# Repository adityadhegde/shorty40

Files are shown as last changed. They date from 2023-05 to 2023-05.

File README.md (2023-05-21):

# The Shorty40
An ortholinear 39key keyboard with a 2U spacebar and KMK support using a Raspberry Pi Pico

## Bill of Materials

### Cost Saving Open Build
* Printed circuit board
* Raspberry Pi Pico or clones with same dimensions and GPIO Layouts with male headers attached 
* 39 1N4148 Diodes - through hole version
* 39 CherryMX Compatible plate mount switches
* 38 1U Keycaps and 1 2U Keycaps
* 1 2U plate mount stabilizer
* 1 3D Printed key plate
* 1 Laser Cut bottom plate
* 4 M2 Stand-Offs with  minimum 20mm clearance
* 8 5mm M2 screws
* 4 adhesive silicone/rubber foot - recommended but not required

### Close Case Build
* Printed circuit board
* Raspberry Pi Pico or clones with same dimensions and GPIO Layouts 
* 2 20 Pin male headers for the Pi Pico
* 2 20 Pin male to female headers for PCB
* 39 1N4148 Diodes - through hole version
* Hot Swap Sockets - tested with Millmax 0305 Socket
* 39 CherryMX Compatible plate mount switches
* 38 1U Keycaps and 1 2U Keycaps
* 1 2U plate mount stabilizer
* 1 3D Printed key plate
* 1 3D Printed Case - testing in process
* 8 5mm M2 screws
* 4 adhesive silicone/rubber foot

## Software Setup
1. Install [circuit python](https://circuitpython.org/)
2. Get [KMK](https://github.com/KMKfw/kmk_firmware/archive/refs/heads/master.zip) and unzip the files on to the circuit-python/pi-pico drive
3. Replace the code.py and boot.py files on the Pi-Pico drive with the ones provided on this repository

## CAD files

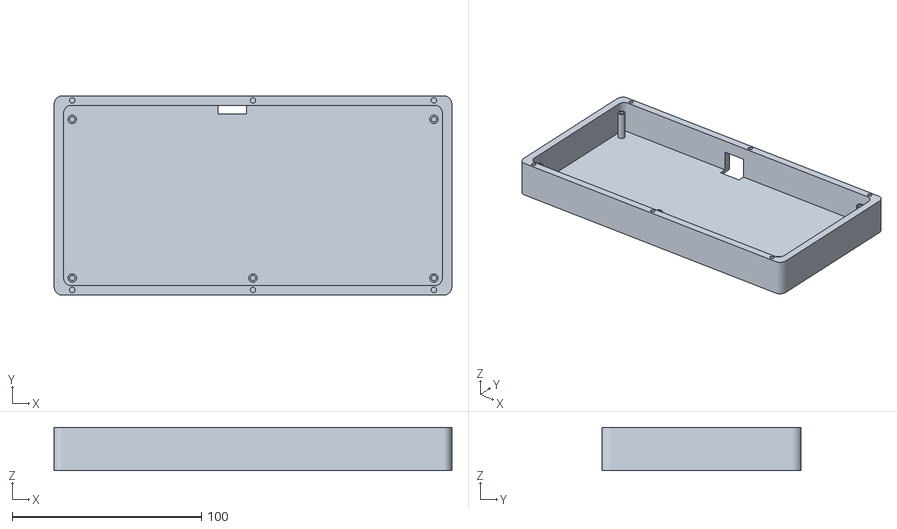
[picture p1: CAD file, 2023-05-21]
case.stl
210.5 x 105.4 x 23.0

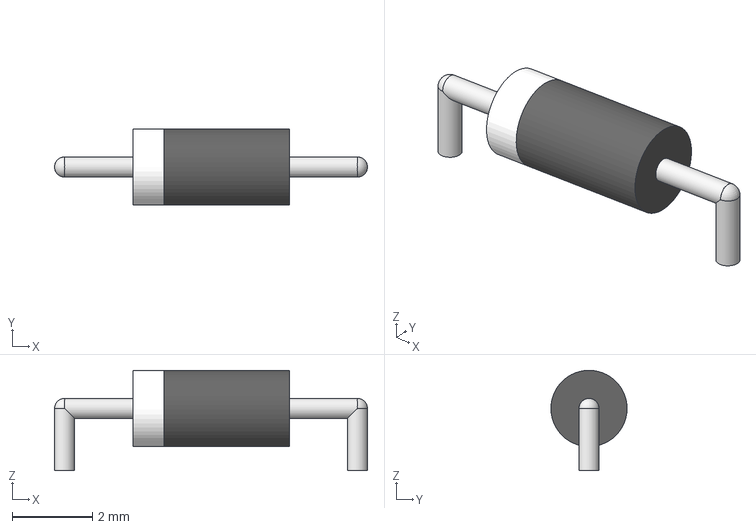
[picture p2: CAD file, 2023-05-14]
keeb/dioade/eec.models/Diotec_Semiconductor_-_1N4148.step
7.80 x 1.90 x 2.50 mm

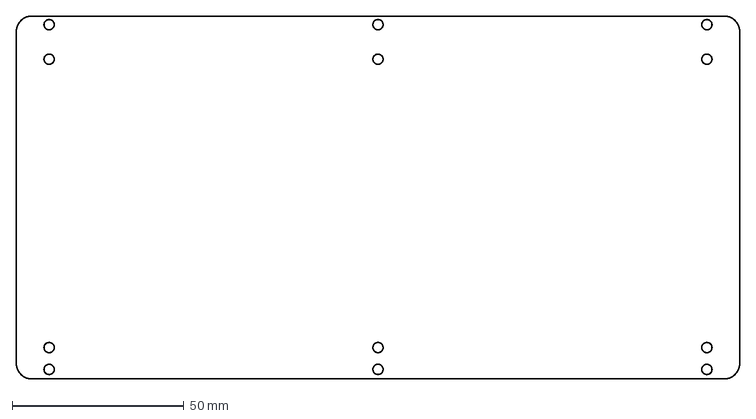
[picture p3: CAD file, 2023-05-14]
bottom_plate.dxf
210.5 x 105.4 mm

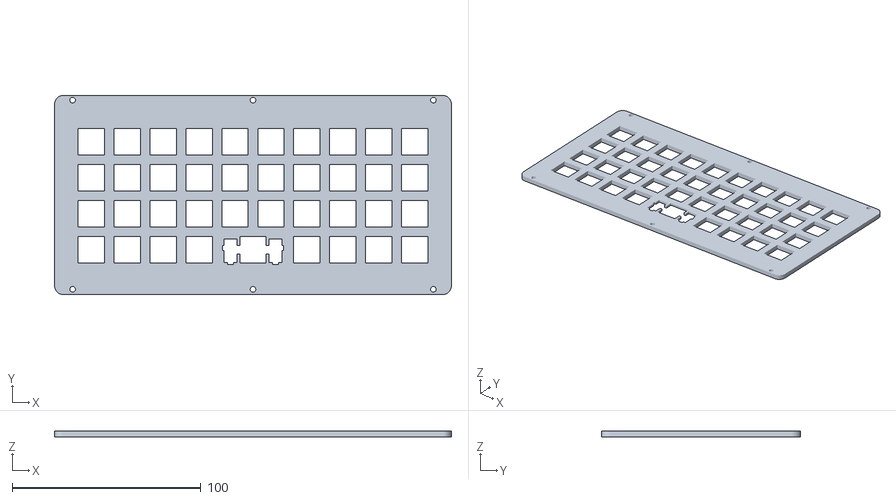
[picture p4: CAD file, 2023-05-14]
plate.stl
210.5 x 105.4 x 3.00

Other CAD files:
keeb/KiCad-RP-Pico-main/SketchUp Model/Pico.skp

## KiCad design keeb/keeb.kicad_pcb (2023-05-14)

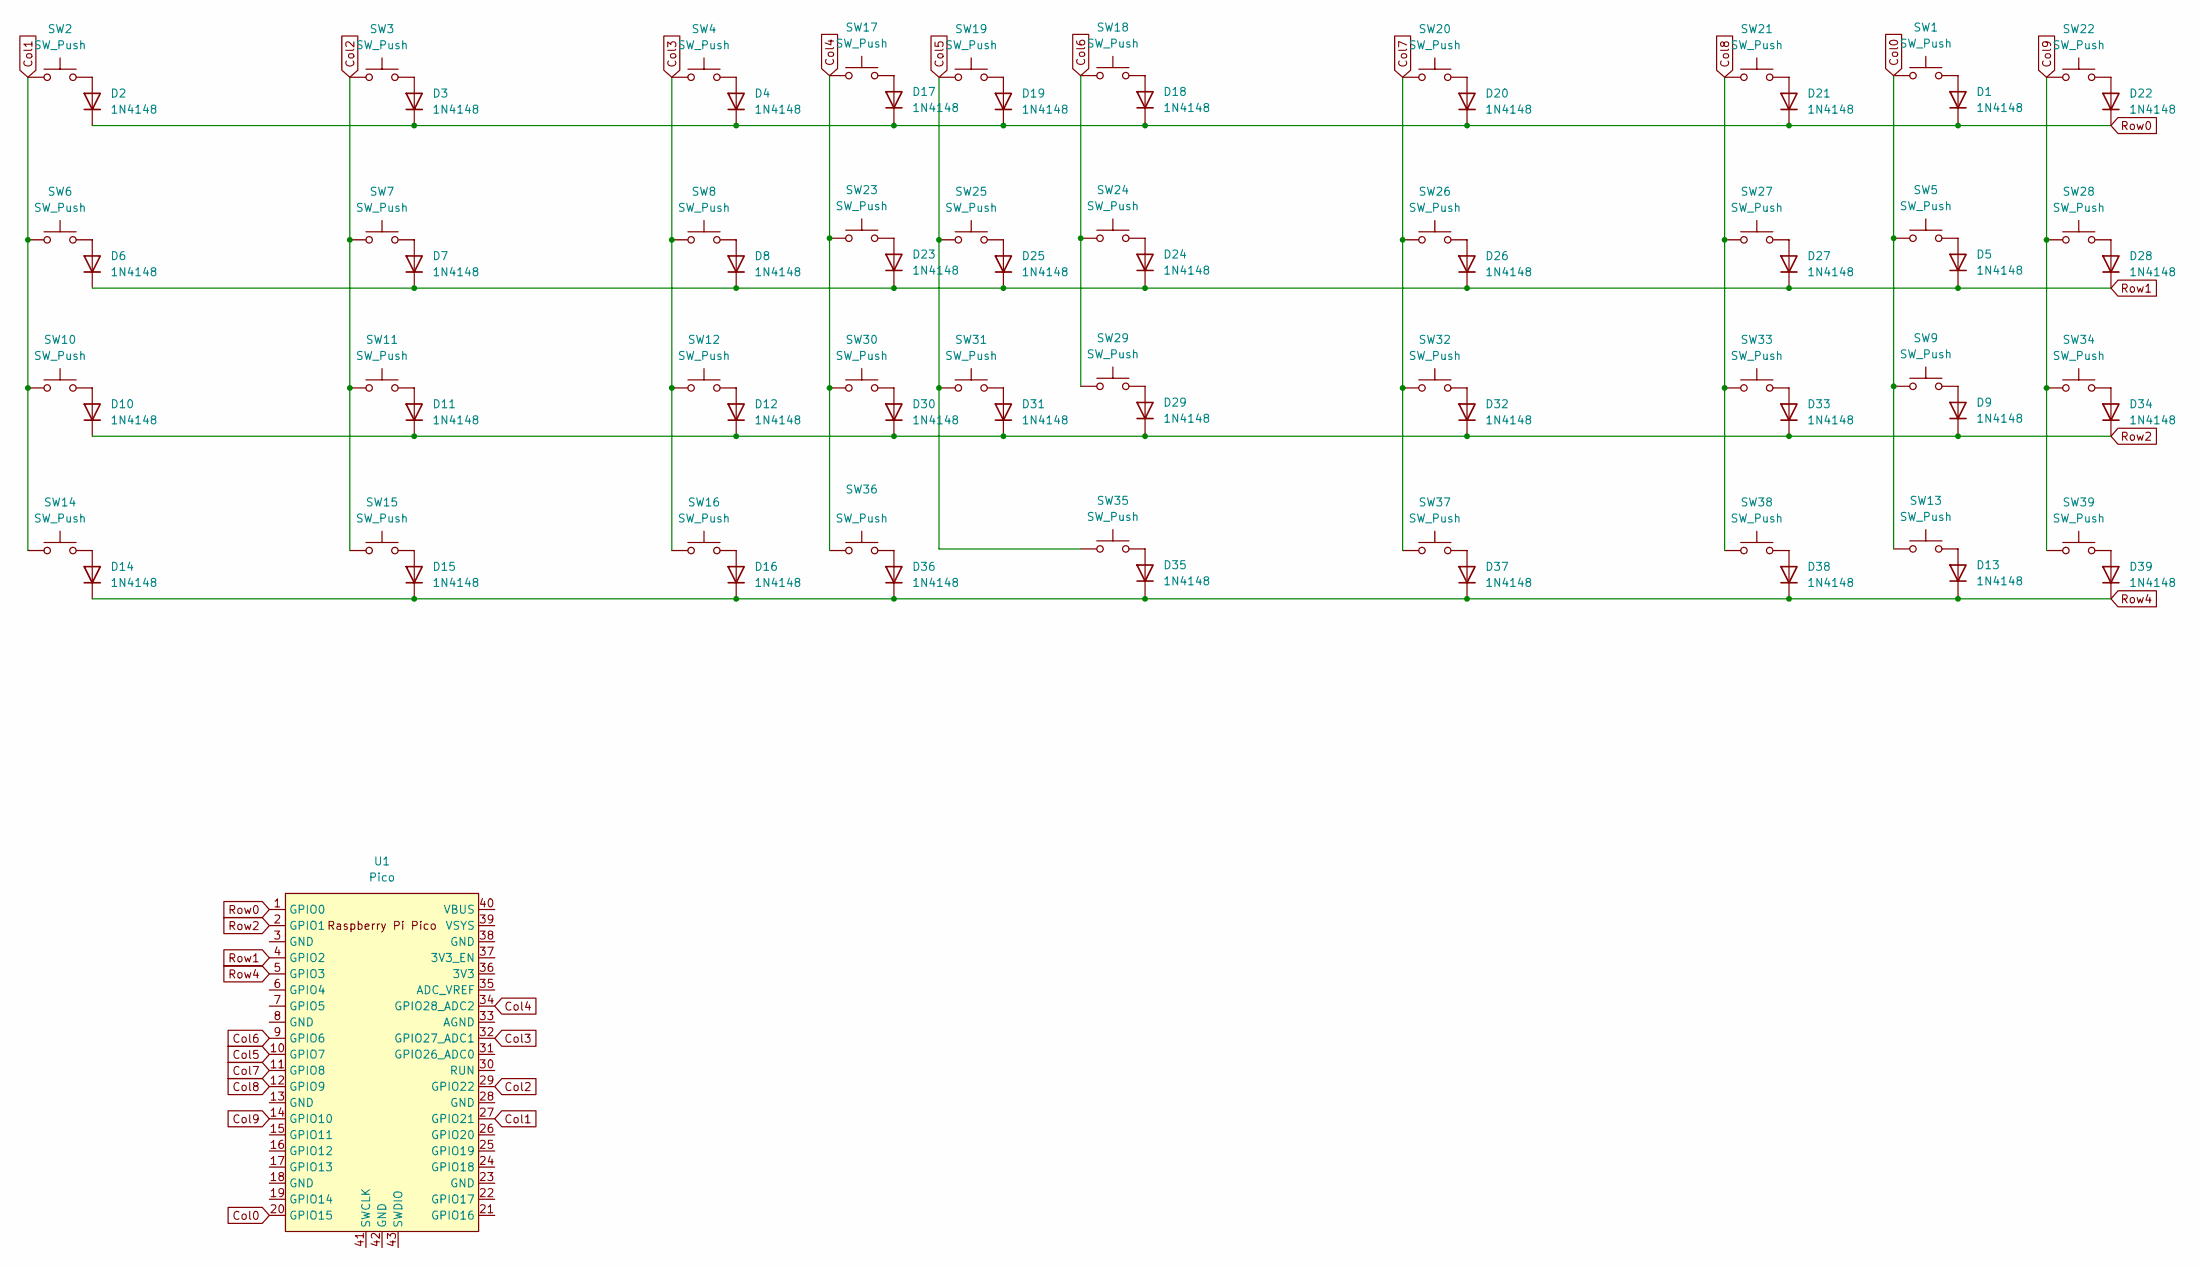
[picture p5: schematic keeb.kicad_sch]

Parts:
D1, D2, D3, D4, D5, D6, D7, D8, D9, D10, D11, D12, D13, D14, D15, D16, D17, D18, D19, D20, D21, D22, D23, D24, D25, D26, D27, D28, D29, D30, D31, D32, D33, D34, D35, D36, D37, D38, D39: 1N4148; Diotec_Semiconductor-1N4148-0
SW1, SW2, SW3, SW4, SW5, SW6, SW7, SW8, SW9, SW10, SW11, SW12, SW13, SW14, SW15, SW16, SW17, SW18, SW19, SW20, SW21, SW22, SW23, SW24, SW25, SW26, SW27, SW28, SW29, SW30, SW31, SW32, SW33, SW34, SW36, SW37, SW38, SW39: SW_Push; SW_Cherry_MX_1.00u_PCB
SW35: SW_Push; SW_Cherry_MX_2.00u_Plate
U1: Pico; RPi_Pico_SMD_TH

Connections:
Col0: SW1.1, SW5.1, SW9.1, SW13.1, U1.20 (GPIO15)
Col1: SW2.1, SW6.1, SW10.1, SW14.1, U1.27 (GPIO21)
Col2: SW3.1, SW7.1, SW11.1, SW15.1, U1.29 (GPIO22)
Col3: SW4.1, SW8.1, SW12.1, SW16.1, U1.32 (GPIO27_ADC1)
Col4: SW17.1, SW23.1, SW30.1, SW36.1, U1.34 (GPIO28_ADC2)
Col5: SW19.1, SW25.1, SW31.1, SW35.1, U1.10 (GPIO7)
Col6: SW18.1, SW24.1, SW29.1, U1.9 (GPIO6)
Col7: SW20.1, SW26.1, SW32.1, SW37.1, U1.11 (GPIO8)
Col8: SW21.1, SW27.1, SW33.1, SW38.1, U1.12 (GPIO9)
Col9: SW22.1, SW28.1, SW34.1, SW39.1, U1.14 (GPIO10)
unnamed: D1.2 (A), SW1.2
unnamed: D2.2 (A), SW2.2
unnamed: D3.2 (A), SW3.2
unnamed: D4.2 (A), SW4.2
unnamed: D5.2 (A), SW5.2
unnamed: D6.2 (A), SW6.2
unnamed: D7.2 (A), SW7.2
unnamed: D8.2 (A), SW8.2
unnamed: D9.2 (A), SW9.2
unnamed: D10.2 (A), SW10.2
unnamed: D11.2 (A), SW11.2
unnamed: D12.2 (A), SW12.2
unnamed: D13.2 (A), SW13.2
unnamed: D14.2 (A), SW14.2
unnamed: D15.2 (A), SW15.2
unnamed: D16.2 (A), SW16.2
unnamed: D17.2 (A), SW17.2
unnamed: D18.2 (A), SW18.2
unnamed: D19.2 (A), SW19.2
unnamed: D20.2 (A), SW20.2
unnamed: D21.2 (A), SW21.2
unnamed: D22.2 (A), SW22.2
unnamed: D23.2 (A), SW23.2
unnamed: D24.2 (A), SW24.2
unnamed: D25.2 (A), SW25.2
unnamed: D26.2 (A), SW26.2
unnamed: D27.2 (A), SW27.2
unnamed: D28.2 (A), SW28.2
unnamed: D29.2 (A), SW29.2
unnamed: D30.2 (A), SW30.2
unnamed: D31.2 (A), SW31.2
unnamed: D32.2 (A), SW32.2
unnamed: D33.2 (A), SW33.2
unnamed: D34.2 (A), SW34.2
unnamed: D35.2 (A), SW35.2
unnamed: D36.2 (A), SW36.2
unnamed: D37.2 (A), SW37.2
unnamed: D38.2 (A), SW38.2
unnamed: D39.2 (A), SW39.2
Row1: D5.1 (K), D6.1 (K), D7.1 (K), D8.1 (K), D23.1 (K), D24.1 (K), D25.1 (K), D26.1 (K), D27.1 (K), D28.1 (K), U1.4 (GPIO2)
Row2: D9.1 (K), D10.1 (K), D11.1 (K), D12.1 (K), D29.1 (K), D30.1 (K), D31.1 (K), D32.1 (K), D33.1 (K), D34.1 (K), U1.2 (GPIO1)

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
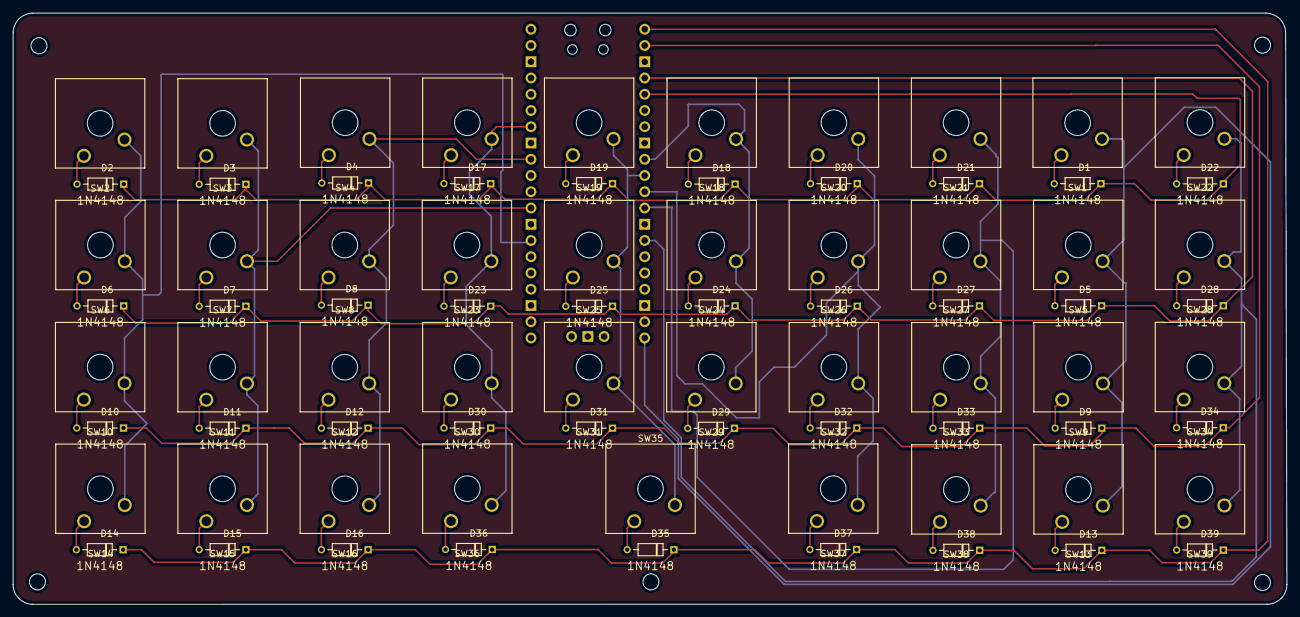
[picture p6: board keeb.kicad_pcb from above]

Board: 2 copper layers, 199.1 x 92.4 mm, 79 parts (1 on the bottom side), 53 nets.

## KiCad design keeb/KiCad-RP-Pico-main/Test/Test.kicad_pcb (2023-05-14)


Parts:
J1, J2: Conn_01x20; PinSocket_1x20_P1.00mm_Vertical
J3: Conn_01x03; PinSocket_1x03_P1.00mm_Vertical
U1: Pico; RPi_Pico_SMD_TH

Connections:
GND: J1.3, J1.8, J1.13, J1.18, J2.3, J2.13, J2.18, J3.2, U1.3 (GND), U1.8 (GND), U1.13 (GND), U1.18 (GND), U1.23 (GND), U1.28 (GND), U1.38 (GND), U1.42 (GND)
unnamed: J1.1, U1.1 (GPIO0)
unnamed: J1.2, U1.2 (GPIO1)
unnamed: J1.4, U1.4 (GPIO2)
unnamed: J1.5, U1.5 (GPIO3)
unnamed: J1.6, U1.6 (GPIO4)
unnamed: J1.7, U1.7 (GPIO5)
unnamed: J1.9, U1.9 (GPIO6)
unnamed: J1.10, U1.10 (GPIO7)
unnamed: J1.11, U1.11 (GPIO8)
unnamed: J1.12, U1.12 (GPIO9)
unnamed: J1.14, U1.14 (GPIO10)
unnamed: J1.15, U1.15 (GPIO11)
unnamed: J1.16, U1.16 (GPIO12)
unnamed: J1.17, U1.17 (GPIO13)
unnamed: J1.19, U1.19 (GPIO14)
unnamed: J1.20, U1.20 (GPIO15)
unnamed: J2.1, U1.40 (VBUS)
unnamed: J2.2, U1.39 (VSYS)
unnamed: J2.4, U1.37 (3V3_EN)
unnamed: J2.5, U1.36 (3V3)
unnamed: J2.6, U1.35 (ADC_VREF)
unnamed: J2.7, U1.34 (GPIO28_ADC2)
unnamed: J2.8, U1.33 (AGND)
unnamed: J2.9, U1.32 (GPIO27_ADC1)
unnamed: J2.10, U1.31 (GPIO26_ADC0)
unnamed: J2.11, U1.30 (RUN)
unnamed: J2.12, U1.29 (GPIO22)
unnamed: J2.14, U1.27 (GPIO21)
unnamed: J2.15, U1.26 (GPIO20)
unnamed: J2.16, U1.25 (GPIO19)
unnamed: J2.17, U1.24 (GPIO18)
unnamed: J2.19, U1.22 (GPIO17)
unnamed: J2.20, U1.21 (GPIO16)
unnamed: J3.1, U1.43 (SWDIO)
unnamed: J3.3, U1.41 (SWCLK)


Board: 2 copper layers, 43.0 x 65.0 mm, 4 parts (0 on the bottom side), 36 nets.

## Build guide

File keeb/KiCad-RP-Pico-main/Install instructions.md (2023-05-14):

# Install instructions

## 1. Copy the files locally

Copy the `RP-Pico Libraries` folder wherever you like on your computer.

## 2. Install the Raspberry Pi Pico board schema symbol

Use the `KiCad | Preferences | Manage Symbol Libraries...` command to manage the symbol library:



then select the global tab and click on the folder button:



navigate to the `RP-Pico Libraries` folder, select the `MCU_RaspberryPi_and_Boards.kicad_sym` file and open it:



et voilà, the first step is completed:



You can now close the symbol libraries manager window.

## 3. Install the Raspberry Pi Pico board footprint

You can use a similar approach to add the footprint to the footprint libraries manager, but I've found some issues that I've solved using the footprint editor, so here are the steps I suggest you to follow:

Open the footprint editor



wait for the footprints to load... then use the `File | Add Library` command:



confirm the `Global` choice:



and select the `MCU_RaspberriPi_and_Boards.pretty` folder (yes, the folder represent a footprint library on KiCad):



Now the library is installed on KiCad with the Raspberry Pi Pico footprint (double click on it to see it on the editor pane):



Don't close the windows as the next step start from here.

## 4. Install the Raspberry Pi Pico board footprint 3D visual

If not already open, open the the footprint editor

symbol library manager

double click on the `RPi_Pico_SMD_TH` footprint from the `MCU_RaspberriPi_and_Boards` library and then click on the `Footprint properties` icon:



In the footprint properties window, first select the `3D Settings` tab. Please note that the preview shows only the PCB board with the footprint added on step 3, without any 3D representation of the Raspberry Pi Pico board. Now click on the folder icon to add the 3D model:



Navigate to the `RP-Pico Libraries` folder, select the `Pico.wrl` file and wait until the model is shown in the right panel, then confirm with OK:



The model is already scaled and translated to match the footprint:



now close the `Footprint Properties` window, and the `Footprint Editor`, obviously saving the changes.

## Conclusion

Now that you've installed the schema and footprint and added the 3D model to the footprint, you can use the Raspberry Pi Pico board on your KiCad projects.

I've also added a test KiCad Project on the `Test` folder, that you can use to see an example of it.

Have fun!

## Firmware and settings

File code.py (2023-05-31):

print("Starting")

import board
from kmk.modules.layers import Layers
from kmk.kmk_keyboard import KMKKeyboard
from kmk.keys import KC
from kmk.scanners import DiodeOrientation
from kmk.extensions.stringy_keymaps import StringyKeymaps
from kmk.modules.modtap import ModTap
from kmk.modules.string_substitution import StringSubstitution



rollover_cols_every_rows = 4


keyboard = KMKKeyboard()
keyboard.extensions.append(StringyKeymaps())
keyboard.modules.append(Layers())

modtap = ModTap()
keyboard.modules.append(modtap)

translations = {
    ':data':"""import pandas as np
import numpy as np""",


    ':viz':"""from bokeh.models import ColumnDataSource, HoverTool
from bokeh.plotting import figure

fig=figure()
""",


    ':email':"""from email import encoders
from email.mime.text import MIMEText
from email.mime.base import MIMEBase
from email.mime.multipart import MIMEMultipart
from email.utils import formatdate
import smtplib
from email.mime.application import MIMEApplication

send_from = 'placeholder@domain.com'
send_to = 'placeholder@domain.com'

msg = MIMEMultipart()
msg["From"] = send_from
msg["To"] = send_to
msg["Subject"] = '{{{placeholder}}}'

message = '{{{placeholder}}}'
message = MIMEText(message, "plain")
msg.attach(message)

s = smtplib.SMTP()
s.connect(host="smtp.domain.com")
s.sendmail(send_from, send_to.split(","), msg.as_string())
s.close()

""",


    ':sign':"""Thank You,
John Doe""",


    ':mysql':"""import mysql.connector
from sqlalchemy import create_engine
import urllib


host='{{{placeholder}}}'
user='{{{placeholder}}}'
password='{{{placeholder}}}'
database = '{{{placeholder}}}'
sql = '{{{placeholder}}}'

engine = create_engine('mysql+pymysql://{user}:{psw}@{host}/{db}'.format(user=user,host=host,db=database,psw=urllib.parse.quote(password)))
data = pd.read_sql(sql, engine)

engine.dispose()
""",


    ':redshift':"""import redshift_connector
import urllib


host='{{{placeholder}}}'
user='{{{placeholder}}}'
password='{{{placeholder}}}'
database = '{{{placeholder}}}'
port = '{{{placeholder}}}'
sql = '{{{placeholder}}}'

conn = redshift_connector.connect(host= host,port= port,database= database,user= user,password= password)
data = pd.read_sql(sql, conn)

conn.dispose()
"""
}

string_substitution = StringSubstitution(dictionary = translations)

keyboard.modules.append(string_substitution)

keyboard.col_pins = (
    board.GP28,board.GP27,board.GP26,
    board.GP22,board.GP7,board.GP6,
    board.GP8,board.GP9,board.GP15,board.GP10
    )
keyboard.row_pins = (
    board.GP3,board.GP2,board.GP1,board.GP0
    )
keyboard.diode_orientation = DiodeOrientation.COL2ROW
______ = 'NO'

MOLYR = KC.MO(1)

switchwinmod = KC.MT(KC.LGUI(KC.TAB),MOLYR)
bswitchwinclt = KC.MT(KC.LGUI(KC.LSFT(KC.TAB)),KC.LCTL)

switchtabgui = KC.MT(KC.LCTL(KC.TAB),KC.LGUI)
bswitchtabsft = KC.MT(KC.LCTL(KC.LSFT(KC.TAB)),KC.LSFT)
altesc = KC.MT( KC.ESC, KC.LALT)
keyboard.keymap = [
    [
        "Q",'W','E','R','T','Y','U','I','O','P',
        'A','S','D','F','G','H','J','K','L','ENT',
        'Z','X','C','V','B','N','M','COMMA','DOT','QUOTE',
        switchwinmod,bswitchwinclt,switchtabgui,bswitchtabsft,'SPC',______,altesc,'SCOLON','MINUS','BSPC' 
    ],
    [
        "F1",'F2','F3','F4','F5','F6','F7','F8','F9','TAB',
        "N1",'N2','N3','N4','N5','N6','N7','N8','N9','N0',
        'F10','F11','F12','BSLASH','GRAVE','SLASH','EQL','LBRC','RBRC','ESC',
        MOLYR,'RCTL','LGUI','RSFT','SPC',______,'LEFT','DOWN','UP','RIGHT' 
    ],

]

if __name__ == '__main__':
    keyboard.go()

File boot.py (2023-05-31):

import supervisor
import board
import digitalio
import storage
import usb_cdc
import usb_hid

from code import keyboard
from kmk.scanners import DiodeOrientation


# If this key is held during boot, don't run the code which hides the storage and disables serial
# This will use the first row/col pin. Feel free to change it if you want it to be another pin
col = digitalio.DigitalInOut(board.GP28)
row = digitalio.DigitalInOut(board.GP3)

if keyboard.diode_orientation == DiodeOrientation.COLUMNS:
    col.switch_to_output(value=True)
    row.switch_to_input(pull=digitalio.Pull.DOWN)
else:
    col.switch_to_input(pull=digitalio.Pull.DOWN)
    row.switch_to_output(value=True)

if not row.value:
    storage.disable_usb_drive()
    # Equivalent to usb_cdc.enable(console=False, data=False)
    usb_cdc.disable()
    usb_hid.enable(boot_device=1)

row.deinit()
col.deinit()


# import board

# from kmk.bootcfg import bootcfg

# bootcfg(
#     sense=board.GP28,  # column
#     source=board.GP2, # row
#     boot_device = 1,
#     midi=False,
#     mouse=False,
#     storage=False,
#     usb_id=('CoffeeSippingBastard', 'Shorty40'),
# )

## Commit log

2023-05-14 BOM and corrections
2023-05-21 case modifications, removed standoff near the pico and adjusted the USB port cut off
    [case.stl]
2023-05-21 updated keymap to add LALT key and box brackets
2023-05-31 fixed issues with boot file leading to fail while hiding storage
    [boot.py]
